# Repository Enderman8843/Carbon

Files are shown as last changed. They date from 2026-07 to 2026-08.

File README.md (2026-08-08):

# Carbon 
4A5A74

## Why did I build this 
As we know my nations air quality is pretty bad therefore I decided to make a air quality analyser to know the actual depth of this danger specially for my home 

## How to Use this 
First connect this device via usb-c cable to your pc then download the firmware files `Firmware\BUILD` or build them using the ino file in `firmware` wait for sometime as the BME688 needs sometime to stabilize its reading then after that the neopixels will show the color according to the IAQ of your enviroiment (RED = BAD , GREEN = GOOD , AMBER= MODERATE)

*Note the firmware is untested

## Working 
This takes the reading of the Bosch IAQ sensor and the temperature sensor to give accurate condition of the enviroiment 

## PCB Layout

| PCB Layout | Schematic / Wiring |
| :---: | :---: |
|  |  |

## PCB Render

| Front | Rear |
| :---: | :--: |
|  |  |

## Case

<p align="center">
  
</p>

---

## BOM

| Item | Description | Quantity | Unit Price ($) | Total Price ($) | URL |
|---|---|---|---|---|-----|
| PCBA | Custom PCB Manufacturing (JLCPCB) | 1 | 49.35 | 49.35 | https://jlcpcb.com |
| Case | 3D Printed Case (Will be Printed Myself | 1 | 0.00 | 0.00 | https://hackclub.com |
| ESP-32 C6 Mini-1 | MCU |1 | 4.47 | 4.47 |  https://www.digikey.in/en/products/detail/espressif-systems/ESP32-C6-MINI-1-N4/17885796 |
| BME688 | VOC sensor | 1 | 9 |  9  | https://www.digikey.in/en/products/detail/bosch-sensortec/BME688/13681261|
| **TOTAL** |  |  |  | **63.00** |  |

# JLCPCB and Shipping



---

## BOM PCBA 
# BOM (Bill of Materials)

| Comment | Designator | Footprint | LCSC | Quantity |
|---|---|---|---|---:|
| 0.1uF | C13, C15, C3, C4, C5, C7, C8 | C_0603_1608Metric | C125205 | 7 |
| 10K | R1, R2 | R_0603_1608Metric | C15401 | 2 |
| 10uF | C10, C12, C14, C9 | C_0603_1608Metric | C19702 | 4 |
| 1uF | C11 | C_0603_1608Metric | C15849 | 1 |
| 220Ω | R5 | R_0603_1608Metric | C23179 | 1 |
| 4.7kΩ | R10, R9 | R_0603_1608Metric | C15401 | 2 |
| 47uF | C6 | C_0603_1608Metric | C140782 | 1 |
| 5.1kΩ | R6, R7 | R_0603_1608Metric | C23186 | 2 |
| 74AHCT1G125SE-7 | U7 | SOT-353_L2.2-W1.4-P0.65-LS2.4-BR | C151417 | 1 |
| AP2112K-3.3TRG1 | U5 | SOT-25-5_L2.9-W1.6-P0.95-LS2.8-BL | C51118 | 1 |
| AP2120N-1.8TRG1 | U4 | SOT-23_L2.9-W1.3-P1.90-LS2.4-BR | C460317 | 1 |
| BME688 | U6 | LGA-8_L3.0-W3.0-P0.80_BME688 | C3664478 | 1 |
| ENS210 | U1 | AMS_QFN-4-1EP_2x2mm_P0.95mm_EP0.7x1.6mm | C2991202 | 1 |
| ESP32-C6-MINI-1 | U3 | ESP32-C6-MINI-1 | C5736265 | 1 |
| SW_Push | Boot1, Reset1 | SW_SPST_PTS647_Sx38 | C720477 | 2 |
| USB-C Receptacle USB2.0 14P | J1 | USB_C_Receptacle_HRO_TYPE-C-31-M-12 | C5143397 | 1 |
| SK6812MINI | D1 | LED_SK6812MINI_PLCC4_3.5x3.5mm_P1.75mm | — | 1 |
| SK6812MINI | D2 | LED_SK6812MINI_PLCC4_3.5x3.5mm_P1.75mm | — | 1 |

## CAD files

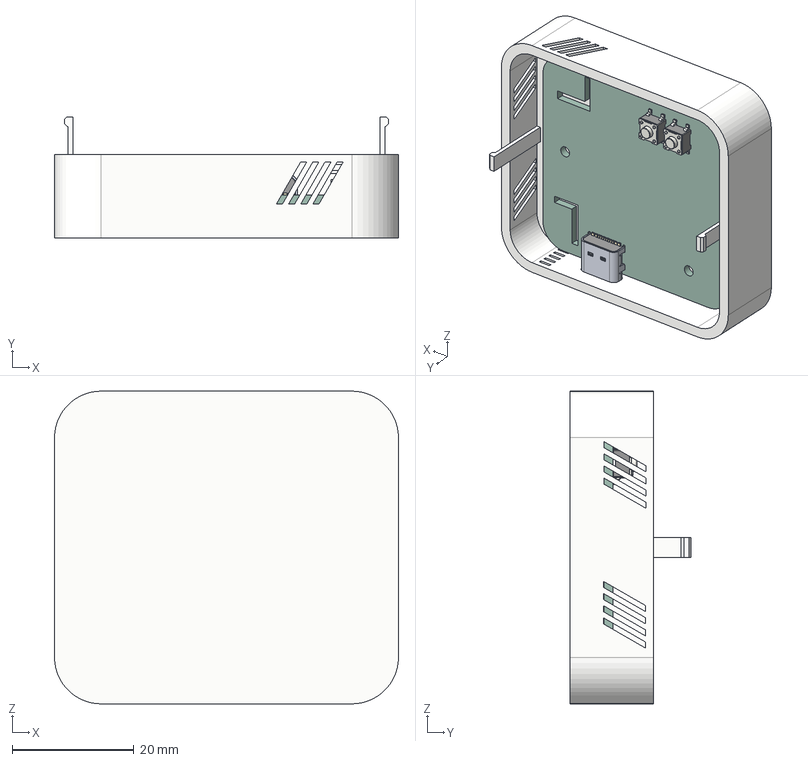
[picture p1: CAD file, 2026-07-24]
CAD/Carbon.step
56.6 x 20.0 x 51.4 mm
SW_SPST_PTS647Sx38 x 2
USB_C_Receptacle_HRO_TYPE-C-31-M-12
Carbon_PCB

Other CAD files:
CAD/Carbon.f3z

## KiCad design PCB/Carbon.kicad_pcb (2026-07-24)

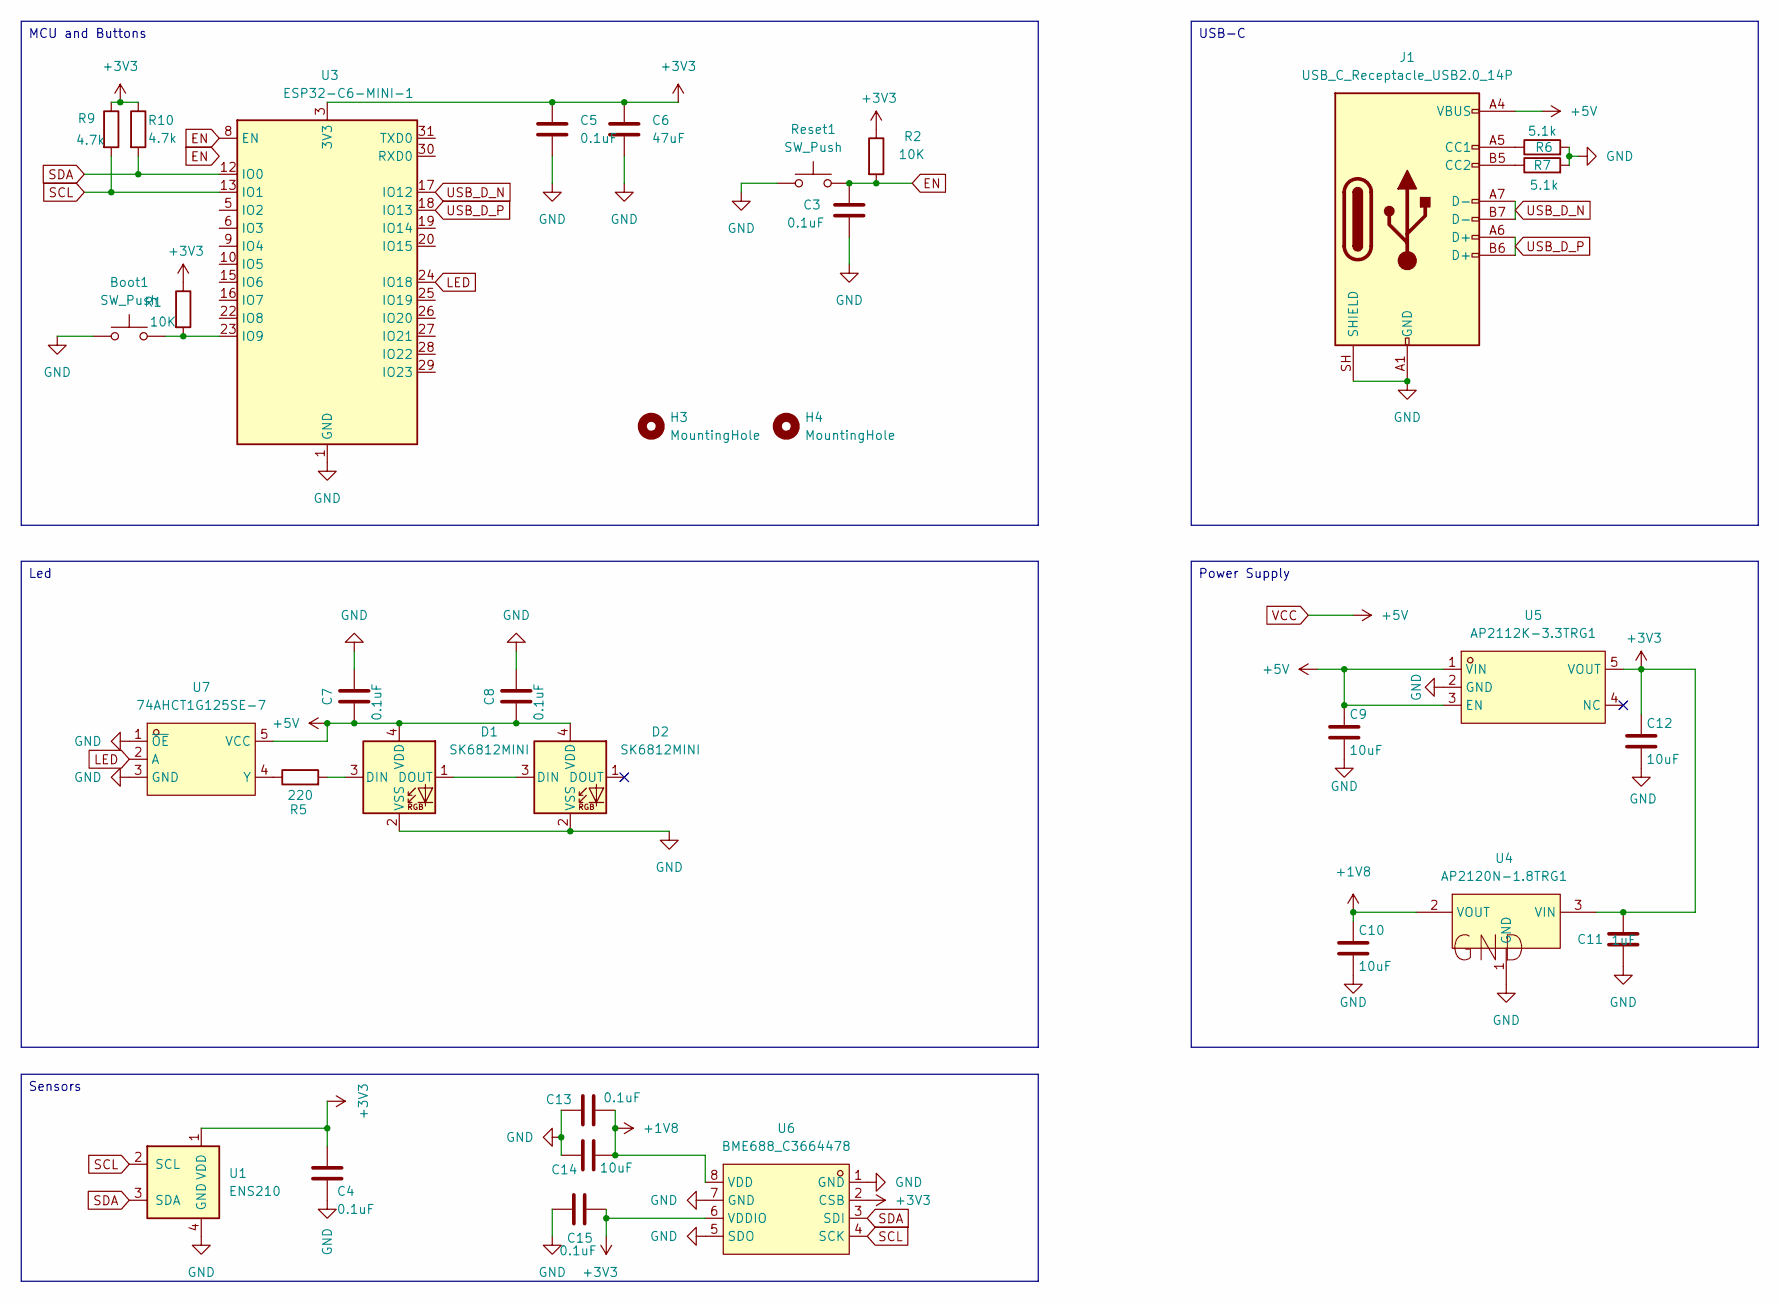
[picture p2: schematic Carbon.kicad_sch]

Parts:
Boot1: SW_Push; SW_SPST_PTS647_Sx38
C3, C4, C5, C7, C8, C13, C15: 0.1uF; C_0603_1608Metric
C6: 47uF; C_0603_1608Metric
C9, C10, C12, C14: 10uF; C_0603_1608Metric
C11: 1uF; C_0603_1608Metric
D1, D2: SK6812MINI; LED_SK6812MINI_PLCC4_3.5x3.5mm_P1.75mm
H3, H4: MountingHole; MountingHole_2.2mm_M2
J1: USB_C_Receptacle_USB2.0_14P; USB_C_Receptacle_HRO_TYPE-C-31-M-12
R1, R2: 10K; R_0603_1608Metric
R5: 220; R_0603_1608Metric
R6, R7: 5.1k; R_0603_1608Metric
R9, R10: 4.7k; R_0603_1608Metric
Reset1: SW_Push; SW_SPST_PTS647_Sx38
U1: ENS210; AMS_QFN-4-1EP_2x2mm_P0.95mm_EP0.7x1.6mm
U3: ESP32-C6-MINI-1
U4: AP2120N-1.8TRG1; SOT-23_L2.9-W1.3-P1.90-LS2.4-BR; MPN AP2120N-1.8TRG1; LCSC Part C460317
U5: AP2112K-3.3TRG1; SOT-25-5_L2.9-W1.6-P0.95-LS2.8-BL; MPN AP2112K-3.3TRG1; LCSC Part C51118
U6: BME688_C3664478; LGA-8_L3.0-W3.0-P0.80_BME688; MPN BME688; LCSC Part C3664478
U7: 74AHCT1G125SE-7; SOT-353_L2.2-W1.4-P0.65-LS2.4-BR; MPN 74AHCT1G125SE-7; LCSC Part C151417

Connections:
+1V8: C10.1, C13.1, C14.1, U4.2 (VOUT), U6.8 (VDD)
+3V3: C4.1, C5.1, C6.1, C11.1, C12.1, C15.2, R1.1, R2.1, R9.1, R10.1, U1.1 (VDD), U3.3 (3V3), U4.3 (VIN), U5.5 (VOUT), U6.2 (CSB), U6.6 (VDDIO)
EN: C3.1, R2.2, Reset1.2, U3.8 (EN)
GND: Boot1.1, C3.2, C4.2, C5.2, C6.2, C7.2, C8.2, C9.2, C10.2, C11.2, C12.2, C13.2, C14.2, C15.1, D1.2 (VSS), D2.2 (VSS), J1.A1 (GND), J1.A12 (GND), J1.B1 (GND), J1.B12 (GND), J1.SH (SHIELD), R6.2, R7.2, Reset1.1, U1.4 (GND), U1.5 (GND), U3.1 (GND), U3.2 (GND), U3.11 (GND), U3.14 (GND), U3.36 (GND), U3.37 (GND), U3.38 (GND), U3.39 (GND), U3.40 (GND), U3.41 (GND), U3.42 (GND), U3.43 (GND), U3.44 (GND), U3.45 (GND), U3.46 (GND), U3.47 (GND), U3.48 (GND), U3.49 (GND), U3.50 (GND), U3.51 (GND), U3.52 (GND), U3.53 (GND), U4.1 (GND), U5.2 (GND), U6.1 (GND), U6.5 (SDO), U6.7 (GND), U7.1 (~OE), U7.3 (GND)
LED: U3.24 (IO18), U7.2 (A)
unnamed: D1.3 (DIN), R5.2
unnamed: D1.1 (DOUT), D2.3 (DIN)
unnamed: J1.A5 (CC1), R6.1
unnamed: J1.B5 (CC2), R7.1
unnamed: Boot1.2, R1.2, U3.23 (IO9)
unnamed: R5.1, U7.4 (Y)
SCL: R9.2, U1.2 (SCL), U3.13 (IO1), U6.4 (SCK)
SDA: R10.2, U1.3 (SDA), U3.12 (IO0), U6.3 (SDI)
USB_D_N: J1.A7 (D-), J1.B7 (D-), U3.17 (IO12)
USB_D_P: J1.A6 (D+), J1.B6 (D+), U3.18 (IO13)
VCC: C7.1, C8.1, C9.1, D1.4 (VDD), D2.4 (VDD), J1.A4 (VBUS), J1.A9 (VBUS), J1.B4 (VBUS), J1.B9 (VBUS), U5.1 (VIN), U5.3 (EN), U7.5 (VCC)

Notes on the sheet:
Led
Sensors
Power Supply
USB-C
MCU and Buttons

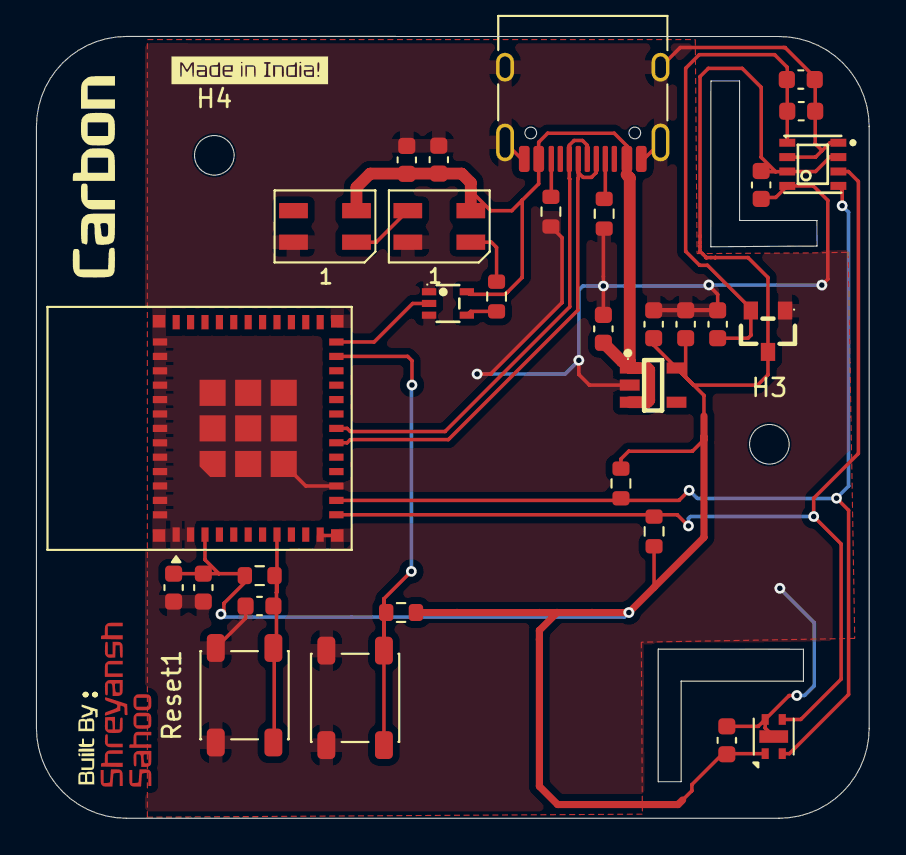
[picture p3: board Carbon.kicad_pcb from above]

Board: 2 copper layers, 46.3 x 43.4 mm, 33 parts (0 on the bottom side), 16 nets.

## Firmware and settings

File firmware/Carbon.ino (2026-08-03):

#include <Arduino.h>
#include <Wire.h>
#include <Adafruit_BME680.h>
#include <Adafruit_NeoPixel.h>

constexpr uint8_t PIN_SDA   = 0;
constexpr uint8_t PIN_SCL   = 1;
constexpr uint8_t PIN_LED   = 18;
constexpr uint8_t PIN_BOOT  = 9;
constexpr uint8_t LED_COUNT = 2;
constexpr uint8_t ENS210_ADDRESS = 0x43;
constexpr uint8_t BME688_ADDRESS = 0x76;
constexpr uint8_t ENS210_REG_PART_ID    = 0x00;
constexpr uint8_t ENS210_REG_SYS_CONTROL= 0x10;
constexpr uint8_t ENS210_REG_SENS_RUN   = 0x21;
constexpr uint8_t ENS210_REG_SENS_START = 0x22;
constexpr uint8_t ENS210_REG_TEMP_VALUE = 0x30;
constexpr uint8_t ENS210_REG_HUM_VALUE  = 0x33;

Adafruit_BME680   bme688;
Adafruit_NeoPixel led_strip(LED_COUNT, PIN_LED, NEO_GRB + NEO_KHZ800);

uint32_t warmup_duration_ms = 180000;
const float humidity_reference = 40.0f;
const float iaq_good_threshold = 65.0f;
const float iaq_medium_threshold = 35.0f;

float    gas_baseline = 0;
bool     is_warmed_up = false;
uint32_t warmup_start_time = 0;

#define CRC7_WIDTH 7
#define CRC7_POLY 0x89u
#define CRC7_INIT 0x7Fu
#define DATA_WIDTH 17
#define DATA_MASK ((1UL<<DATA_WIDTH)-1)
#define DATA_MSB  (1UL<<(DATA_WIDTH-1))

static uint32_t ens210_crc7(uint32_t value){
  uint32_t polynomial = CRC7_POLY<<(DATA_WIDTH-CRC7_WIDTH-1), bit = DATA_MSB;
  value<<=CRC7_WIDTH; bit<<=CRC7_WIDTH; polynomial<<=CRC7_WIDTH; value|=CRC7_INIT;
  while(bit&(DATA_MASK<<CRC7_WIDTH)){ if(bit&value) value^=polynomial; bit>>=1; polynomial>>=1; }
  return value;
}

static bool ens210_write_register(uint8_t register_address, uint8_t value){
  Wire.beginTransmission(ENS210_ADDRESS); Wire.write(register_address); Wire.write(value);
  return Wire.endTransmission()==0;
}

static bool ens210_read_register(uint8_t register_address, uint8_t* buffer, uint8_t length){
  Wire.beginTransmission(ENS210_ADDRESS); Wire.write(register_address);
  if(Wire.endTransmission(false)!=0) return false;
  if(Wire.requestFrom((int)ENS210_ADDRESS,(int)length)!=length) return false;
  for(uint8_t index=0; index<length; index++) buffer[index]=Wire.read();
  return true;
}
static bool ens210_begin(){
  ens210_write_register(ENS210_REG_SYS_CONTROL,0x80); delay(5);
  ens210_write_register(ENS210_REG_SYS_CONTROL,0x00); delay(5);
  uint8_t part_id[2]; if(!ens210_read_register(ENS210_REG_PART_ID,part_id,2)) return false;
  return (uint16_t)(part_id[0]|(part_id[1]<<8))==0x0210;
}
static bool ens210_measure(float& temperature_celsius, float& relative_humidity){
  ens210_write_register(ENS210_REG_SENS_RUN,0x00);
  ens210_write_register(ENS210_REG_SENS_START,0x03);
  delay(130);
  uint8_t temp_bytes[3], humidity_bytes[3];
  if(!ens210_read_register(ENS210_REG_TEMP_VALUE,temp_bytes,3)) return false;
  if(!ens210_read_register(ENS210_REG_HUM_VALUE,humidity_bytes,3)) return false;
  uint32_t temp_raw     = temp_bytes[0]|(temp_bytes[1]<<8)|((uint32_t)temp_bytes[2]<<16);
  uint32_t humidity_raw = humidity_bytes[0]|(humidity_bytes[1]<<8)|((uint32_t)humidity_bytes[2]<<16);
  bool temp_valid     = ((temp_raw>>16)&1)&&(ens210_crc7(temp_raw&0x1FFFF)==((temp_raw>>17)&0x7F));
  bool humidity_valid = ((humidity_raw>>16)&1)&&(ens210_crc7(humidity_raw&0x1FFFF)==((humidity_raw>>17)&0x7F));
  if(!temp_valid||!humidity_valid) return false;
  temperature_celsius = (float)(temp_raw&0xFFFF)/64.0f-273.15f;
  relative_humidity   = (float)(humidity_raw&0xFFFF)/512.0f;
  return true;
}
float compute_iaq(float gas_ohms, float humidity){
  float humidity_score;
  if(humidity < 38)       humidity_score = (humidity/humidity_reference)*25.0f;
  else if(humidity > 42)  humidity_score = ((100.0f - humidity)/(100.0f - humidity_reference))*25.0f;
  else                    humidity_score = 25.0f;
  if(humidity_score < 0)  humidity_score = 0;
  float gas_score = (gas_baseline > 0) ? (gas_ohms/gas_baseline)*75.0f : 0;
  if(gas_score > 75) gas_score = 75;
  if(gas_score < 0)  gas_score = 0;
  return humidity_score + gas_score;
}
static void i2c_scan(){
  Serial.println("I2C scan:");
  uint8_t found_count = 0;
  for(uint8_t address=1; address<127; address++){
    Wire.beginTransmission(address);
    if(Wire.endTransmission()==0){ Serial.printf("  0x%02X\n",address); found_count++; }
  }
  if(!found_count) Serial.println("  (nothing found)");
}
void setup(){
  Serial.begin(115200); delay(300);
  pinMode(PIN_BOOT,INPUT_PULLUP);

  led_strip.begin(); led_strip.setBrightness(40);
  led_strip.fill(led_strip.Color(0,0,8)); led_strip.show();

  Wire.begin(PIN_SDA,PIN_SCL,400000);
  i2c_scan();

  Serial.println(ens210_begin()?"ENS210 ok":"ENS210 FAIL");

  if(bme688.begin(BME688_ADDRESS)){
    bme688.setTemperatureOversampling(BME680_OS_8X);
    bme688.setHumidityOversampling(BME680_OS_2X);
    bme688.setPressureOversampling(BME680_OS_4X);
    bme688.setIIRFilterSize(BME680_FILTER_SIZE_3);
    bme688.setGasHeater(320,150);
    Serial.println("BME688 ok");
  } else {
    Serial.println("BME688 FAIL");
  }

  warmup_start_time = millis();
  Serial.println("Warming up gas sensro...");
}
void set_color(uint8_t red, uint8_t green, uint8_t blue){
  led_strip.fill(led_strip.Color(red,green,blue)); led_strip.show();
}
void loop(){
  float ens_temperature, ens_humidity;
  bool ens_ok = ens210_measure(ens_temperature, ens_humidity);
  bool bme_ok = bme688.performReading();

  Serial.println("----");
  if(ens_ok) Serial.printf("ENS210 : %.2f C  %.1f %%RH\n", ens_temperature, ens_humidity);
  if(bme_ok) Serial.printf("BME688 : %.2f C  %.1f %%RH  %.1f hPa  gas %.1f kOhm\n",
             bme688.temperature, bme688.humidity, bme688.pressure/100.0f, bme688.gas_resistance/1000.0f);

  if(!is_warmed_up){
    if(bme_ok && bme688.gas_resistance > gas_baseline) gas_baseline = bme688.gas_resistance;
    uint32_t seconds_left = (millis()-warmup_start_time < warmup_duration_ms)
                            ? (warmup_duration_ms-(millis()-warmup_start_time))/1000 : 0;
    Serial.printf("warming up... %lus left (baseline %.1f kOhm)\n",
                  (unsigned long)seconds_left, gas_baseline/1000.0f);
    set_color(15,15,15);
    if(seconds_left==0 && gas_baseline>0){ is_warmed_up=true; Serial.println("IAQ active."); }
    delay(2000);
    return;
  }

  if(bme_ok && bme688.gas_resistance > gas_baseline)
    gas_baseline = 0.9f*gas_baseline + 0.1f*bme688.gas_resistance;

  if(bme_ok){
    float iaq_score = compute_iaq(bme688.gas_resistance, bme688.humidity);
    const char* label;
    if(iaq_score >= iaq_good_threshold){ set_color(0,255,0);   label="GOOD  (green)"; }
    else if(iaq_score >= iaq_medium_threshold){ set_color(255,90,0); label="MEDIUM(amber)"; }
    else { set_color(255,0,0); label="BAD   (red)"; }
    Serial.printf("IAQ    : %.0f/100  -> %s\n", iaq_score, label);
  } else {
    set_color(64,0,0);
    Serial.println("IAQ    : BME read fail");
  }

  delay(2000);
}
